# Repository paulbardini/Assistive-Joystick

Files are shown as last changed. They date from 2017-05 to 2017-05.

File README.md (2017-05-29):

# Assistive-Joystick for finite hand movement.

#### This joystick was created as an alternative computer mouse to help a sick family friend. 

#### After battling Guillian-Barre syndrome with a short-term period in induced coma, my friend’s rehabilitation required to re-learn basic hand movements and other physical activities which many of us take for granted.

#### This joystick was designed to sit in the hand while lying in bed. The large button on top of the device reduces the amount of effort required to perform a mouse click, while the joystick creates a more controlled method of positioning the mouse cursor.

#### Apart from helping out a friend, I want this project to be released to the community, within an open source ideology, in hope that this may help others in similar situation, or used in ways that are not intended here.

#### Please – take this idea and recreated it. Modify/redesign it to be used for an alternative reason.  With the help of an open community, this project could assist many people in need.

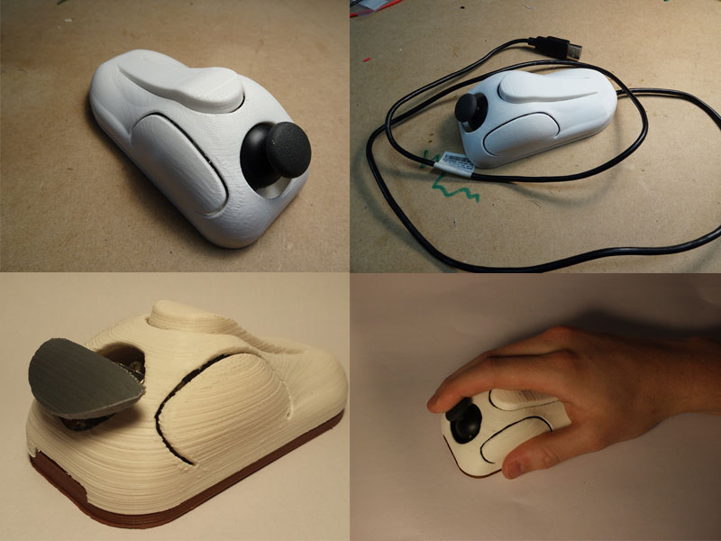
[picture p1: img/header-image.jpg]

>
><b> This project was created by collaborating with the family member. See some of the research photos and discussions.</b>
>### [RESEARCH AND OBSERVATION](https://github.com/paulbardini/Assistive-Joystick/blob/master/Research/Design.md)
>
><b> The large button on the back of the device allows the user to use their palm for the mouse click. The side buttons function by squeezing the device. </b>
><b> A new finger rest was designed to replace the existing joystick knob, allowing the two or three fingers to move the joystick. </b>
>### [IMAGES OF USE](https://github.com/paulbardini/Assistive-Joystick/blob/master/img/Functionality/Use.md)
>
><b> To keep within an open acessible framework, electronic conponents and fabrication was kept within generic conponents and techniques. </b>
><b> Arduino micro controller and stock (very accessible) joystick parts and switches where used to allow for easy replication of the device </b>
>
><b> All CAD source files have been included [link](/CAD%20files).</b>
><b> Please fork this design and/or push changes that helps you and maybe others. </b>
>### [HOW TO MAKE THE ASSISTIVE JOYSTICK - THE HARDWARE](https://github.com/paulbardini/Assistive-Joystick/blob/master/making/README.md)
> 
> ### [HOW TO MAKE THE ASSISTIVE JOYSTICK - THE SOFTWARE](https://github.com/paulbardini/Assistive-Joystick/tree/master/Code)
> 
>
>
***

#### THIS IS AN ONGOING PROJECT AND I AM ASKING FOR HELP TO FURTHER THIS TECHNOLOGY.
#### PLEASE NOTE THAT THIS IS ASSOCIATED WITH A UNIVERSITY RESEARCH PROJECT  
#### PLEASE READ THE FOLLOW ETHIC PROTOCOLS.

****

##### Research Description
This research seeks to better understand the open source framework and how it can be incorporated within the creative arts field to further innovation.
Open source is a paradigm of open collaboration and sharing, where ideas are developed within communities. These communities allow their ideas to be freely available for anyone to replicate, adapt or innovate upon the initial concept. Open source is commonly associated with the computer industry and is often misunderstood to be 'free and accessible software.' However, this definition is limited. Open source, correctly framed, is the dissemination of knowledge, an ideology of openness, transparency and innovation.
To create an understanding of how ideas can be disseminated within the open communities, this research project seeks to experiment with an online collaboration platform called Github, (https://github.com). This platform, traditionally used within software development, allows users to publicly share their work, encouraging collaboration and potential innovation. Although the GitHub is being utilised within other disciplines outside of software, there is great scope to investigate how the creative arts can benefit from this established and tested platform.   
The intention is to use GitHub to disseminate current and future project information, in order to investigate:
-	How people use this information.  Whether the published information is replicated or modified.
-	Ways in which this information is modified. Is the information used in unintentional ways?
GitHub structure allows the research to 
-	Communicate research objectives and information to participation. GitHub facilitates a comprehensive licencing protocol, allowing users to establish licencing agreements. This will also enable the communication of research intentions and information to participants about their involvement within the research project.
-	Follow people's use of the information (within the constraints of the GitHub platform). Through built-in analytics, traffic to GitHub can be tracked and reported.
-	GitHub has built-in chat, commenting and wiki facilities to collaborate with participants. As it is a membership based platform, members can be easily identified and contacted.

##### Participatory information.
THIS GITHUB REPOSITORY IS A UNIVERSITY RESEARCH PROJECT 
This research seeks to better understand the open source framework, and to observe how concepts and ideas, published within this repository, are used. All information within this repository is open for the participant to modify, change and innovate. However, it is encouraged, that all future iterations of this project is to be published within a BRANCH of the master repository. 
Please read the following statement to understand your participatory requirements. 
By BRANCHING – COMMENTING – PULLING - PUSHING – COPYING and other function associated with this GitHub repository, you are agreeing to be a participant of this project. This information should remain intact within any future iterations.
Your confidentiality
All information that identifies the participant within this project will be altered for anonymity, within any publication or reporting i.e. no user name or profile information will be published outside of this repository. For your privacy within GitHub please refer to https://help.github.com/articles/github-privacy-statement/ .
No analysis data from this research will be published within this repository. All research data will be achieved within the appropriate data storage system of Griffith University Australia.
###### Participation is Voluntary
Your participation within this project is voluntary, and you can withdraw from the study at any time. You have the right to delete any of your own contributed data. 
###### Potential Risks
There are no foreseeable risks associated with participation in this research
Questions / further information
All enquiries can be sent to the associated contact details attached to this repository.
The ethical conduct of this research
Griffith University conducts research in accordance with the National Statement on Ethical Conduct in Human Research.  If potential participants have any concerns or complaints about the ethical conduct of the research project they should contact the Manager, Research Ethics on +617 3735 4375 or research-ethics@griffith.edu.au
Communication of Results / Reporting
All participants will be able to request materials relevant to their involvement, during and after the completion of the project.  
Contact Details Research Team
###### Researcher:  Paul Bardini - paul.bardini@griffithuni.edu.au
###### Research Supervisor: Dr Beck Davis - beck.davis@griffith.edu.au

###### Research Data Storage
All research data will be archived within the appropriate data storage system of Griffith University Australia for a period of five years.
Griffith University Research Ethics Clearance Number:  2016/858

<br />This work is licensed under a <a rel="license" href="http://creativecommons.org/licenses/by/4.0/">Creative Commons Attribution 4.0 International License</a>.

https://creativecommons.org/licenses/by/4.0/

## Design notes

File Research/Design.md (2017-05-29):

This project was developed to help a friend rehabitiate from a autoimmune condition Guillain-Barré syndrome (https://www.betterhealth.vic.gov.au/health/conditionsandtreatments/guillain-barre-syndrome)

The project is created within an open source ideology, whereby, all the information to produce this device, is shared for anyone to use, create and modify.

Through research, it was found that the development of such product would usual fall outside the effective time the product would be requires. In other words, by the time the necessary research, development, concepts, prototype and creation occurs the patient, in this case, had already been rehabilitated.

This lends to question whether or not products should be developed in the first place. Well, to answer that question, we need to ask WHO ELSE could benifit from the idea.

#### Observations and Design Intent
The following are images of prototyping - with foam etc - to understand what form the assistive joystick would need to be.

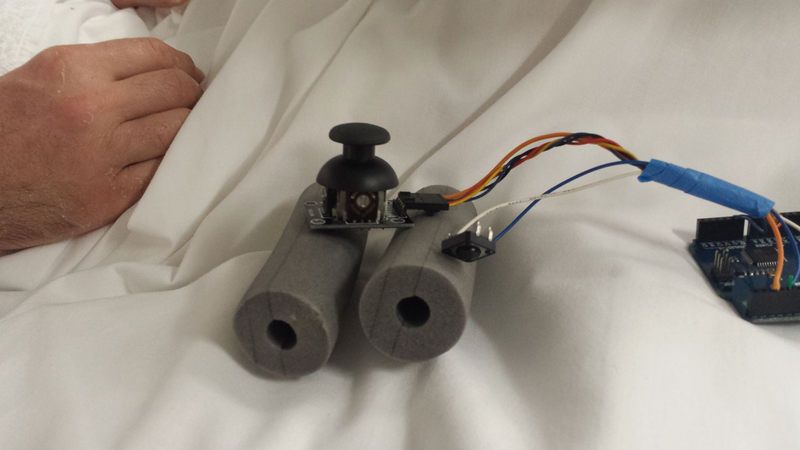
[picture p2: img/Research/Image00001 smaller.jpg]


The strength of the patient was very limited, as was dexterity. 
This led to design the devices to 
- utilised the limited strength of the patient.
- to conrespond to the reaction time and dexerity of the patient.
- ergonomics of hand in a laying positon
- use of open hardware to assist with the acessibility of other coping the device.

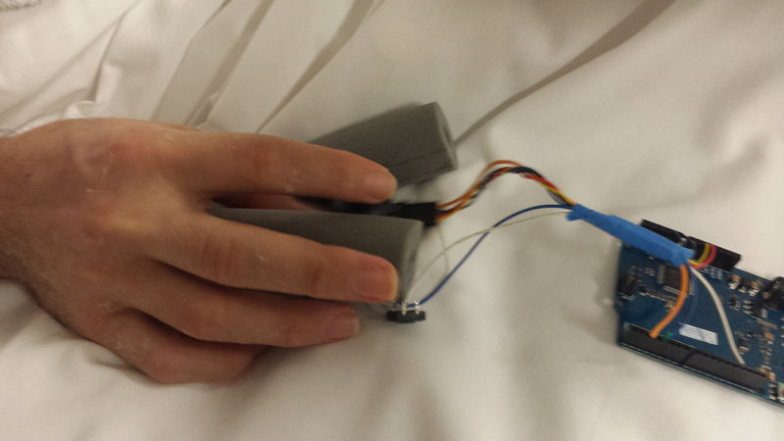
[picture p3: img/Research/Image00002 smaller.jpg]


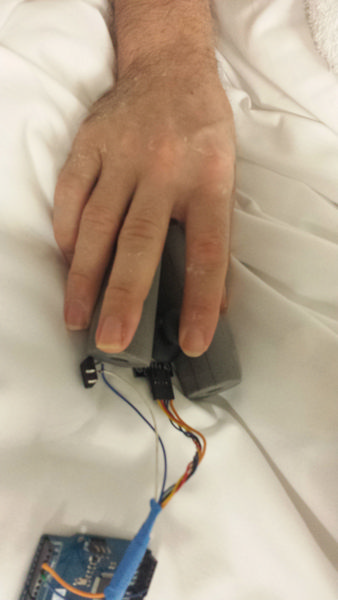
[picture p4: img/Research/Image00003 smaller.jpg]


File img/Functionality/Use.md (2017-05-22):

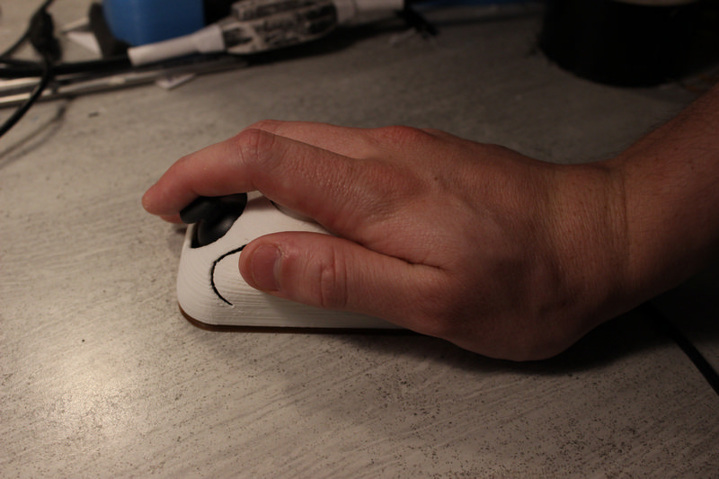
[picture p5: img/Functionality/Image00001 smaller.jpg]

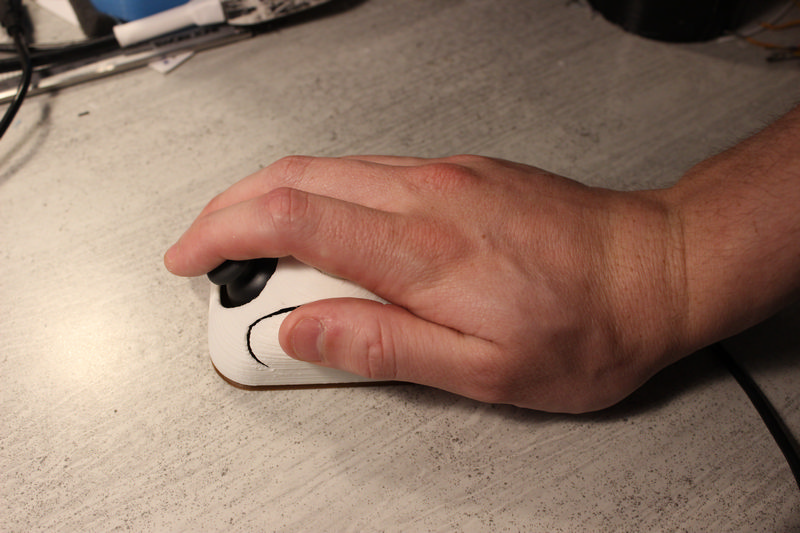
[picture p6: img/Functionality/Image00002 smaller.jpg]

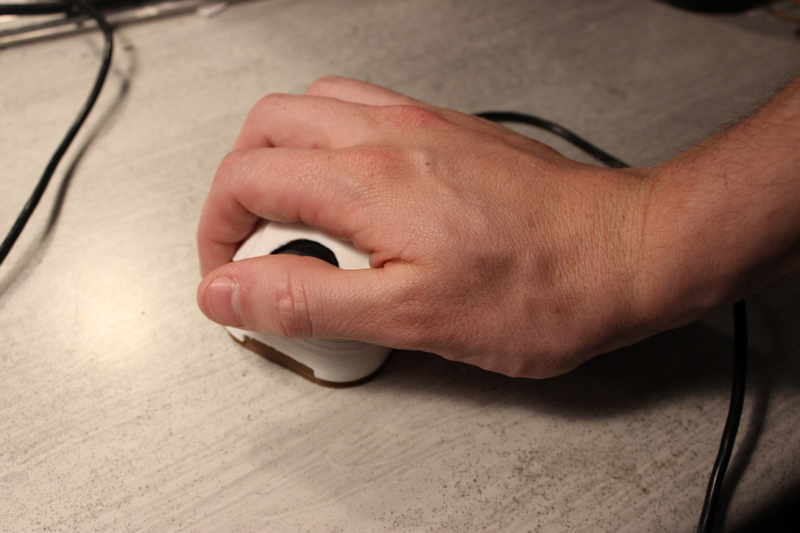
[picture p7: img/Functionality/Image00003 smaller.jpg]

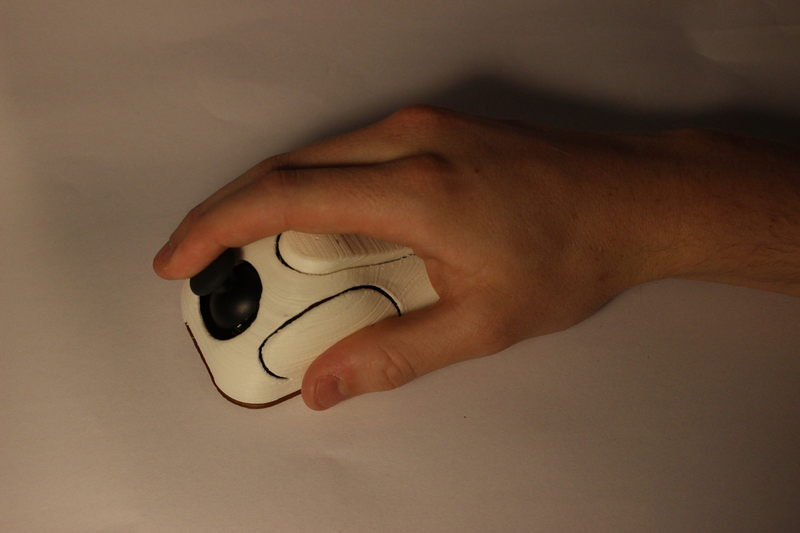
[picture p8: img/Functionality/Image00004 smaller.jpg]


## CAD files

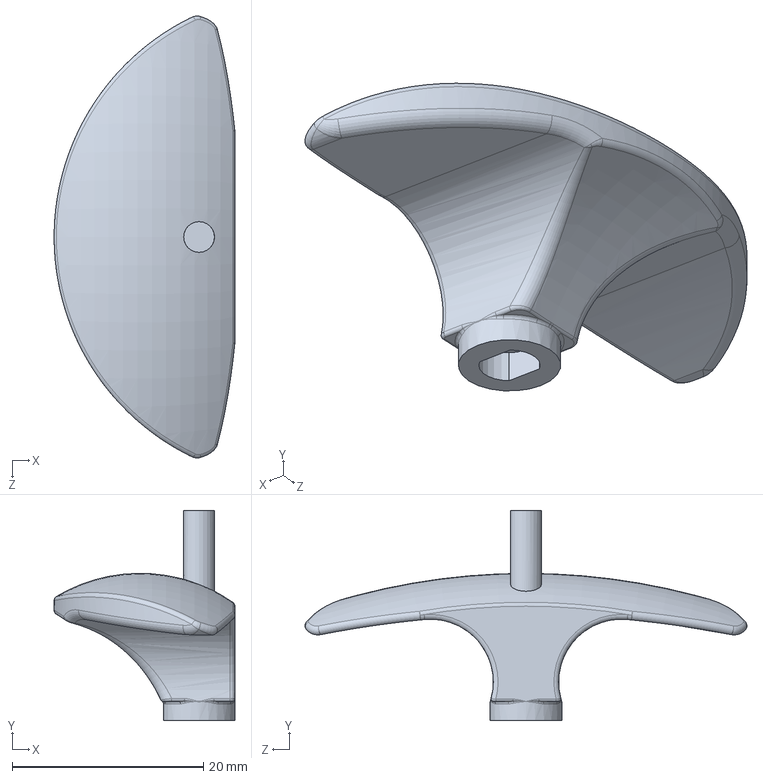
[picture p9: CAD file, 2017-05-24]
CAD files/finger rest convex.SLDPRT
18.9 x 22.0 x 46.3 mm

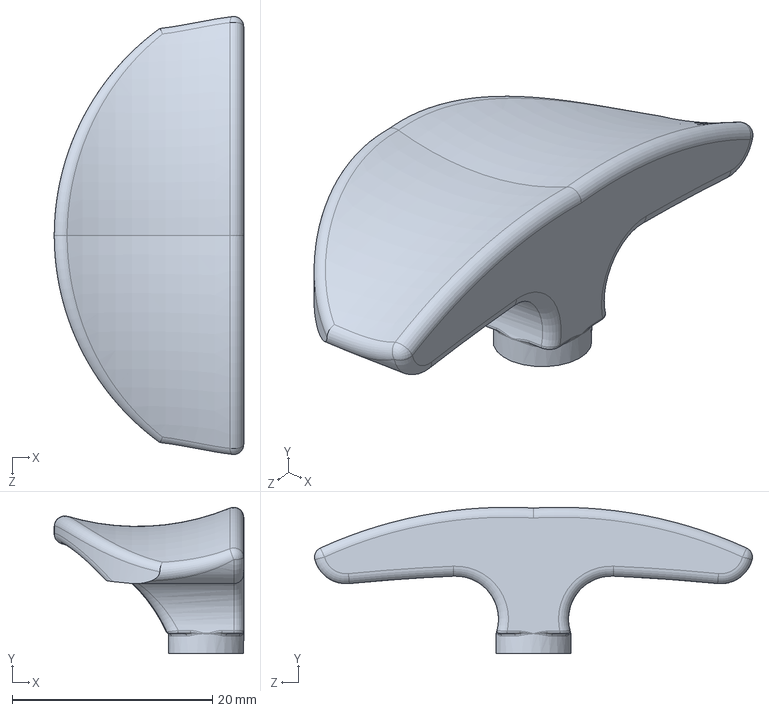
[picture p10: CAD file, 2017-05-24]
CAD files/finger rest 2.SLDPRT
18.9 x 14.6 x 43.7 mm

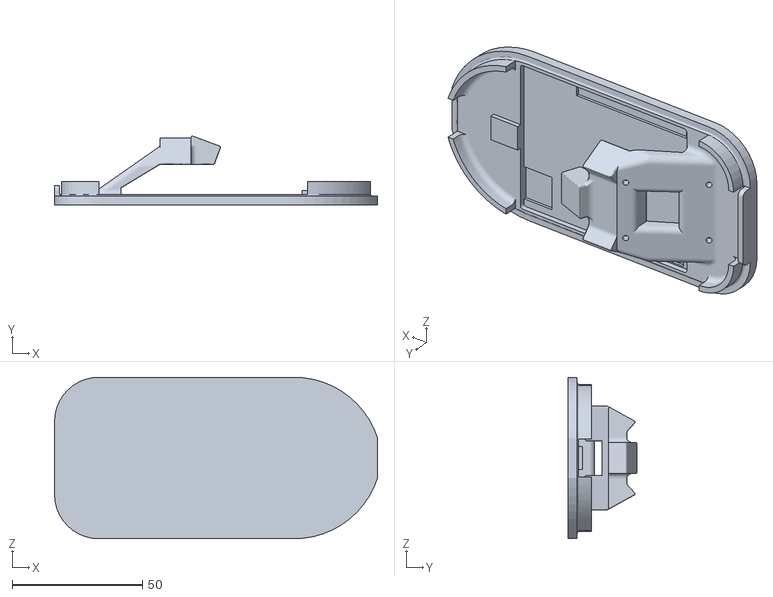
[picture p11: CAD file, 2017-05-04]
CAD files/assistive joystick base.STL
124.0 x 26.4 x 62.0

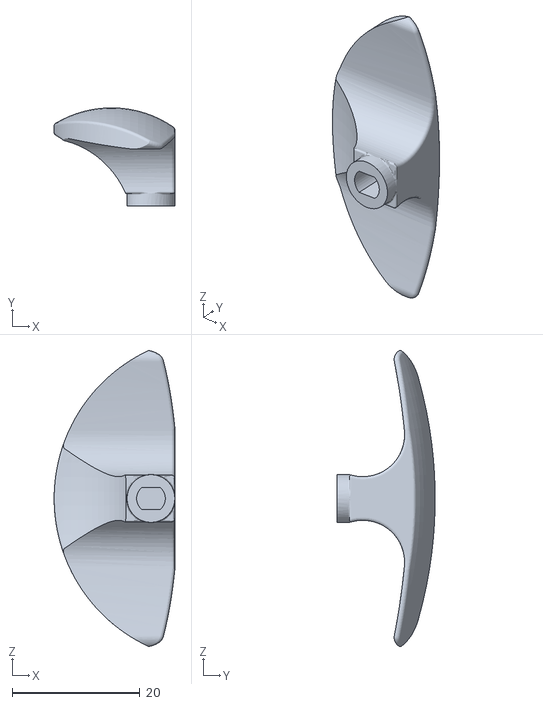
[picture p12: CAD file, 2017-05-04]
CAD files/assistive joystick finger rest.STL
18.9 x 15.4 x 46.4

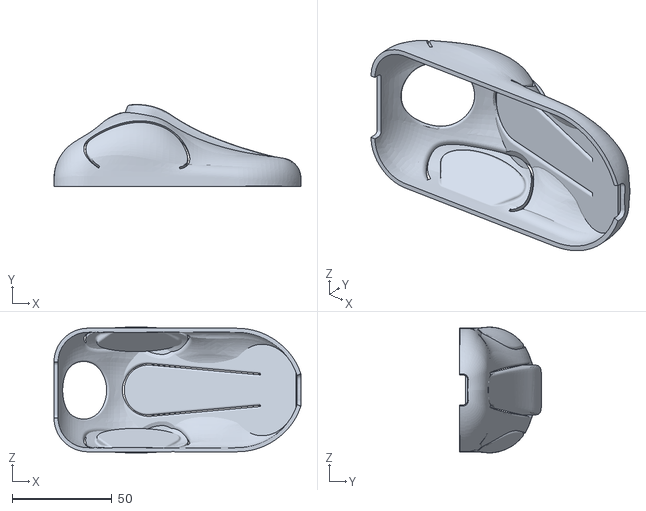
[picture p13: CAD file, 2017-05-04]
CAD files/Assistive Joystick Top Shell.STL
124.0 x 41.1 x 63.2

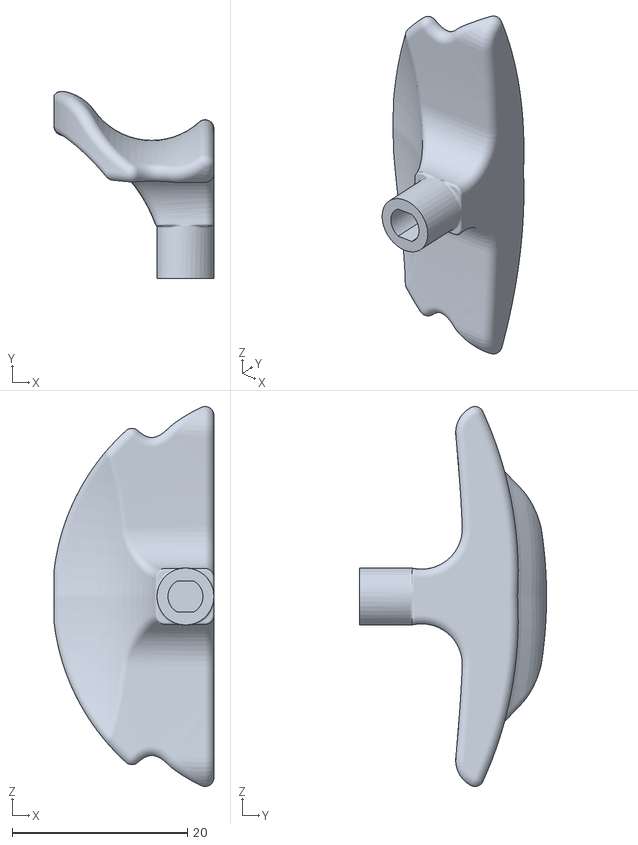
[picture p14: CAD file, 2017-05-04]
CAD files/finger rest.STL
18.2 x 21.4 x 43.4

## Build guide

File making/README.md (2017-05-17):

Hardware

<h1> THIS IS AN ONGOING PROJECT AND I AM ASKING FOR HELP TO FURTHER THIS TECHNOLOGY.</h1>
To Create the Joystick you will require the following materials.

Materials

- Arduino Leonardo - requires the mouse emulator
  - https://www.arduino.cc/en/main/arduinoBoardLeonardo
- Joystick
- 3 tactile push buttons
- hook up cable
- Male Headers

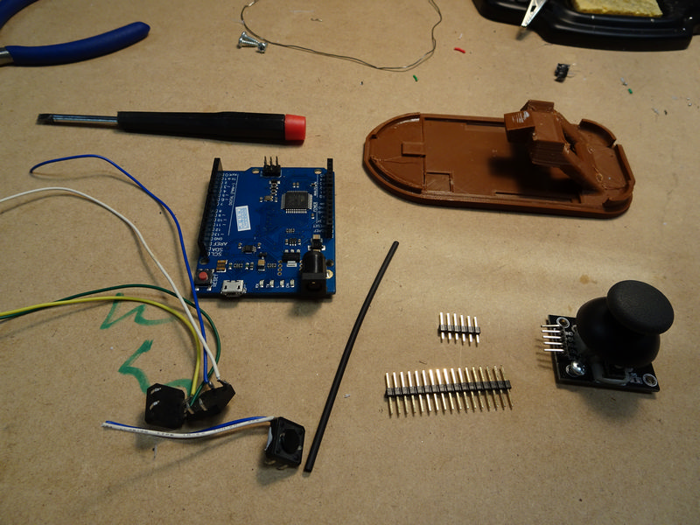
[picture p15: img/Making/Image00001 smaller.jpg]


Tools

- A 3D Printer - or someone to print this for you 
  - Link to STL Files - https://github.com/paulbardini/Assistive-Joystick/tree/master/CAD%20files
  - Link To Thingiverse - http://www.thingiverse.com/thing:1104178/#comment-1287946
  - On-Shape CAD link - https://cad.onshape.com/documents/931052d5d0573c68088a0b20/w/b2adfe2d1f8098bca9e43ab1/e/50dc9f8685308ad67deea490
  
- soldering iron + solder
- wire cutters
- Hot glue gun
- various screws
- screw drivers

<h2> 3D Printing</h2>
You can download the stl file from this link.
https://github.com/paulbardini/Assistive-Joystick/tree/master/CAD%20files

There are two main part to print for the body of the Joystick. I recommend you print these separatley, they take time to print and if it fails then better to loose 1 part and minimal filament.
Both parts will need support, the main body needs a lot of support as most of the body is an overhang. I have done this with an UP Box and the supoort was briliant, much better than my original print as seen on Thingiverse.
I have also printed this in PLA and ABS. Concideration when choosing filament; the mechanical flex in the part is what make the button function.

<h2> Building the electronics</h2>

The joystick uses a Arduino Leonardo - this arduino allows for an intergrated USB HID - in other words it acts like a mouse (or keyboard) 
Attached is 3 tactile buttons and 1 electronic joystick modules. As seen in the picture above.

Below is the Fritzing circuit layout

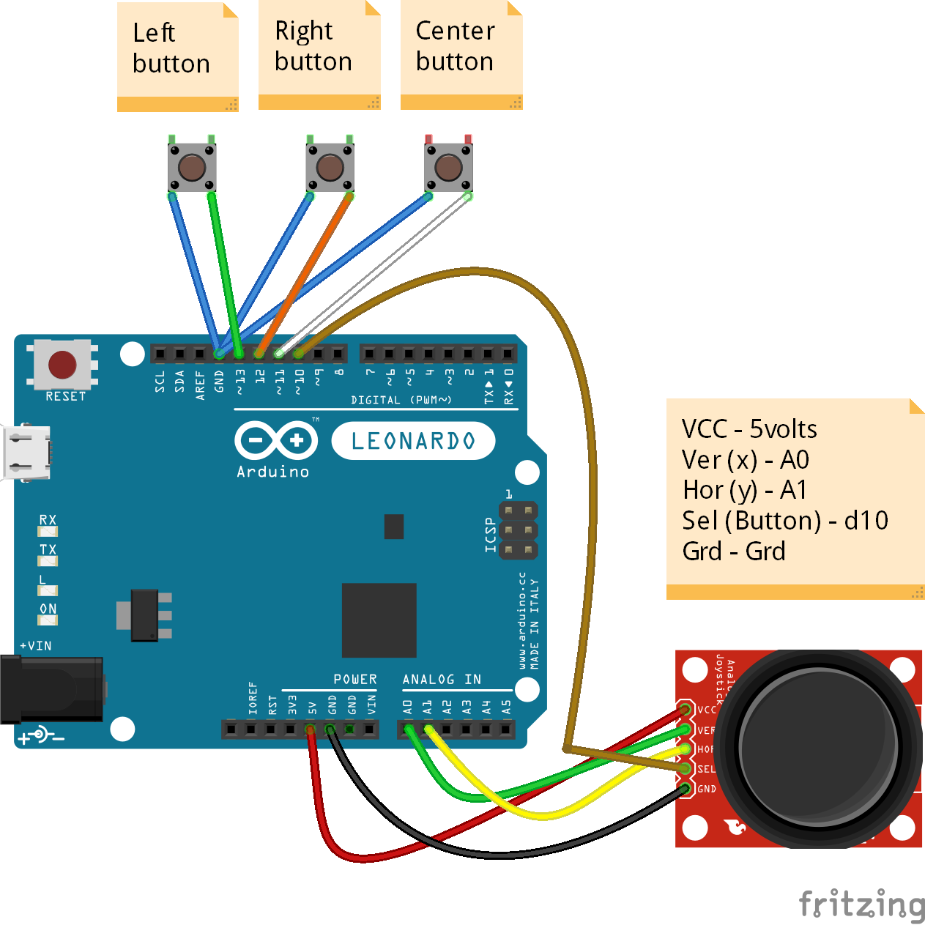
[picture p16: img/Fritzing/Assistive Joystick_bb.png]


<h2> Step 1</h2>

Solder wire onto the Tactile buttons and tie one side together - this will be the button earth/common connection.
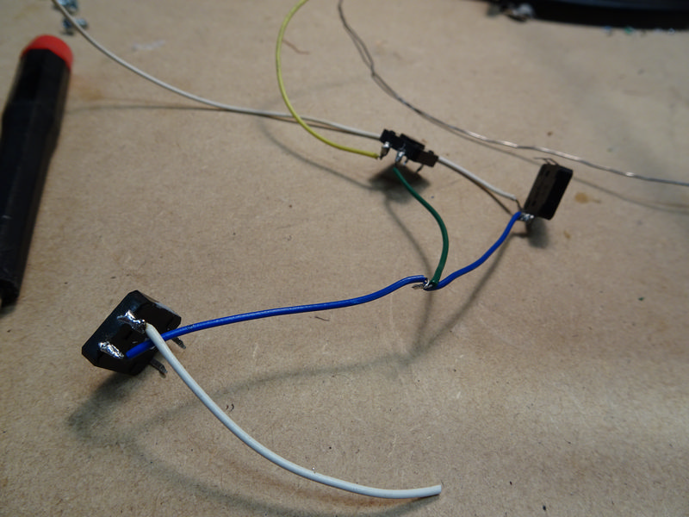
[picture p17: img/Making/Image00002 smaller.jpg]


<h2> Step 2</h2>
Solder all the button wire to a header in order - Common - Button 1 - Button 2 - Button 3.

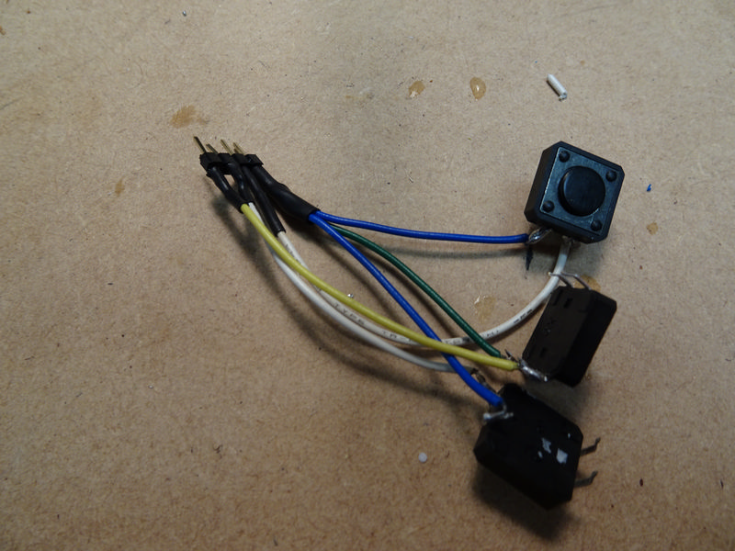
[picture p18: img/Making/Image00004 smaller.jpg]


This will allow the header to plug into the earth - pin13 - pin12 - pin11 of the Arduino. Keeping things neat and tidy.

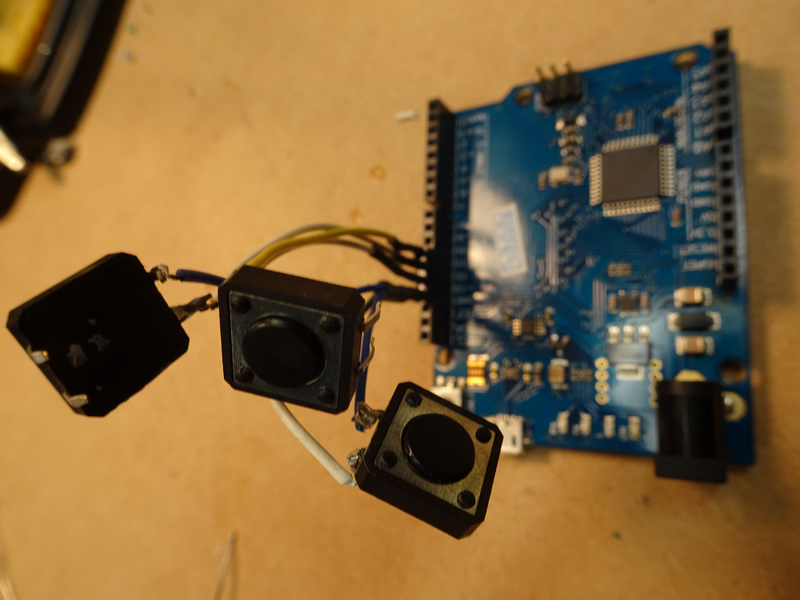
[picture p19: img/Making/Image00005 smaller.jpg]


<h2> Step 3</h2>

<h2> Soldering the joystick.</h2>

The joystick I purchase had header pin pre-connected, this cause problem so I removed them and solder wires straight into the module.
There are 5 connections Earth and VCC (5 volts) X out Y out and the internal switch of the Joystick. 

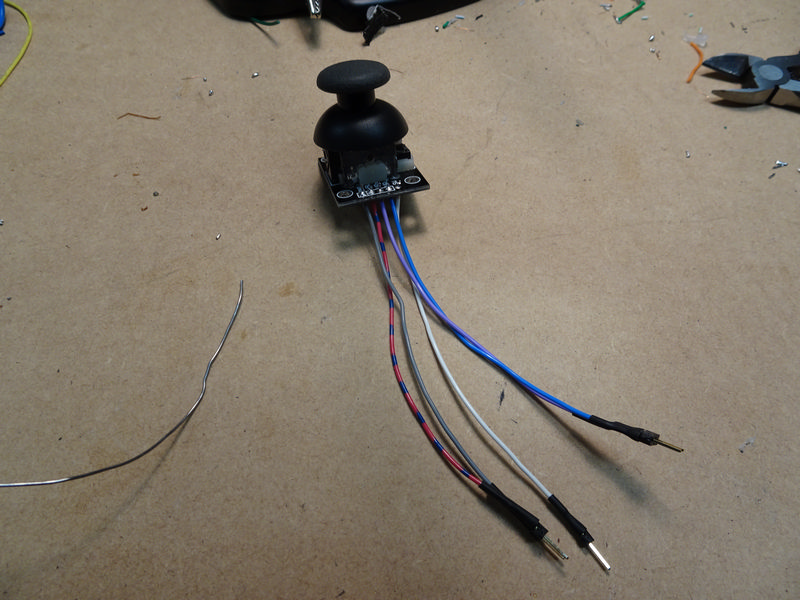
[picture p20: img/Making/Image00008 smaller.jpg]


After soldering the header onto the joystick wires, I used a pair of pliers to remove the platic spacer. This allowed me to bend the header to 90 degrees. There is little room to move with this design, so need to make everyting a tight as possible. As seen in the image below.

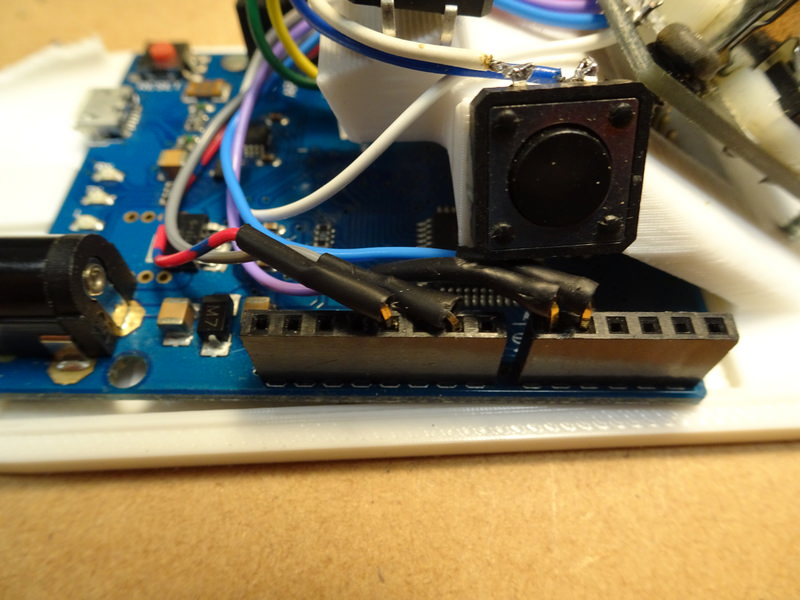
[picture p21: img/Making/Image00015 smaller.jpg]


<h2> Step 4</h2>

<h2> Stuffing it all in</h2>

I did say it was tight, but it does fit. Find a handfull of screw to attach the joystick module to the bottom plate. Be careful, because of the laminating direction of the print, if you use too larger screw it can break/separate the print layer. You also need to pull the joystick module as flat as you can. Be patient - find the rigth screw.

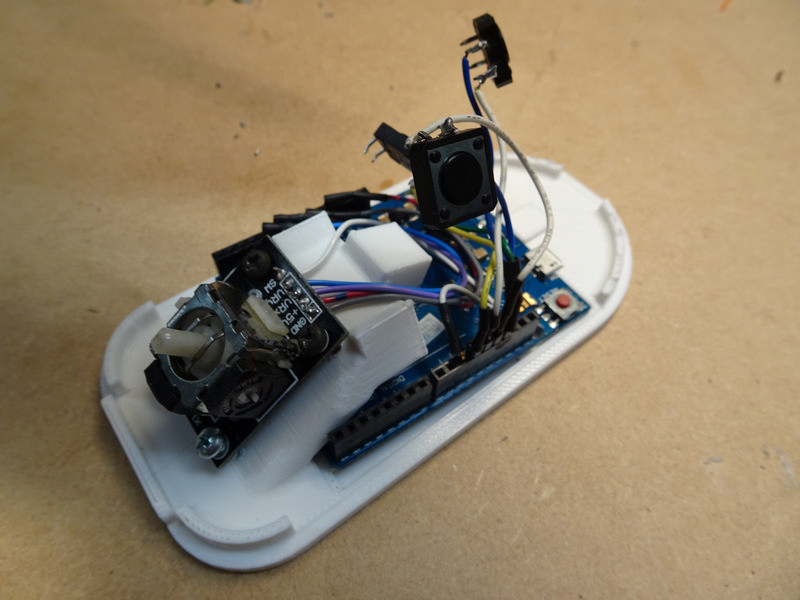
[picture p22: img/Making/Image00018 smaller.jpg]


<h2> Step 5</h2>

<h2> Sticking it down</h2>

I can't say I am a fan of the hot glue gun - overrated in my opinion - but for this case, it works a treat.

Organise your wiring and get everything in the right place before you get glue rage.
I started with the middle button and worked my way round. 

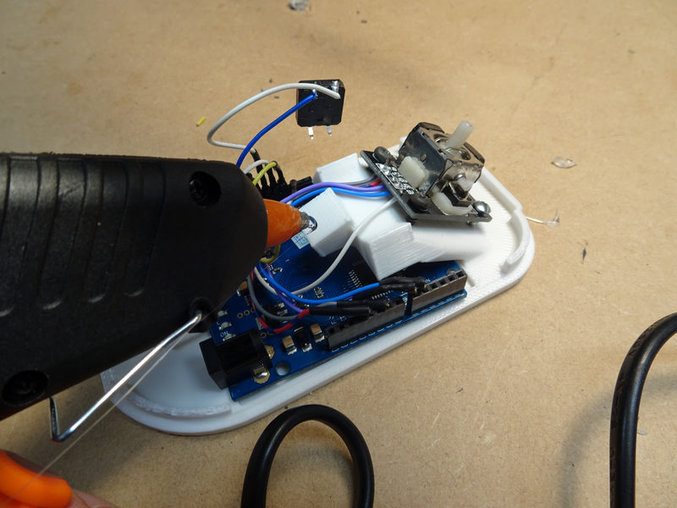
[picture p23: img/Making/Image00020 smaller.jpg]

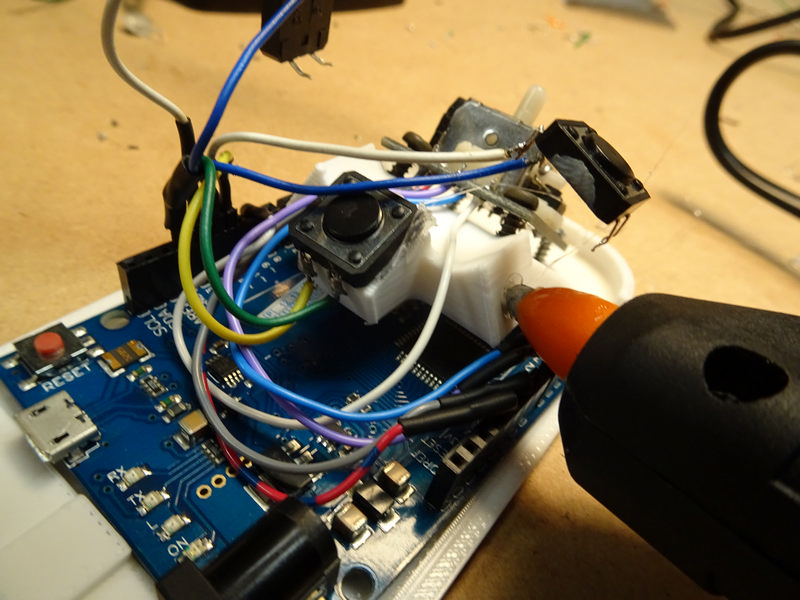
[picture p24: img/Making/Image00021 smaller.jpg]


A bit more glue to hold the wires in place

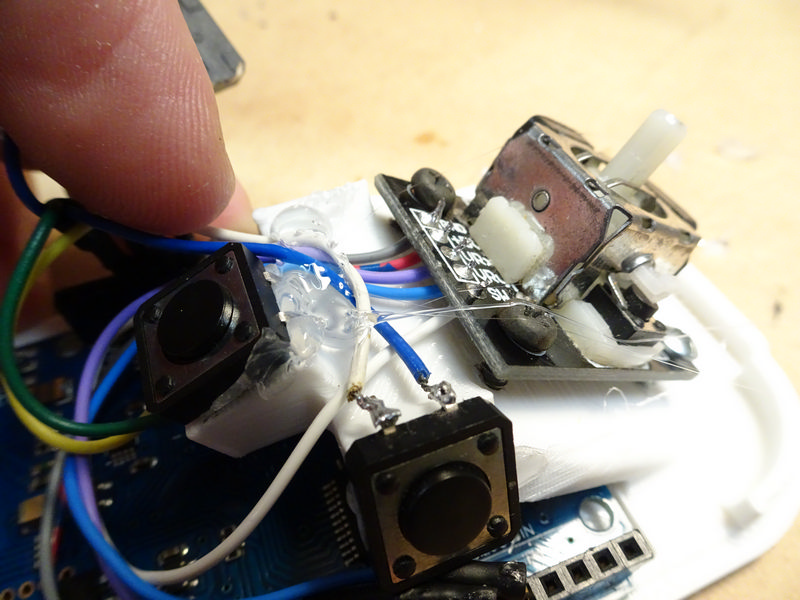
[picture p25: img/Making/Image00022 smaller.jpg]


Now stand back - tend to your burns from the glue gun - and see what you have created.

Behold:

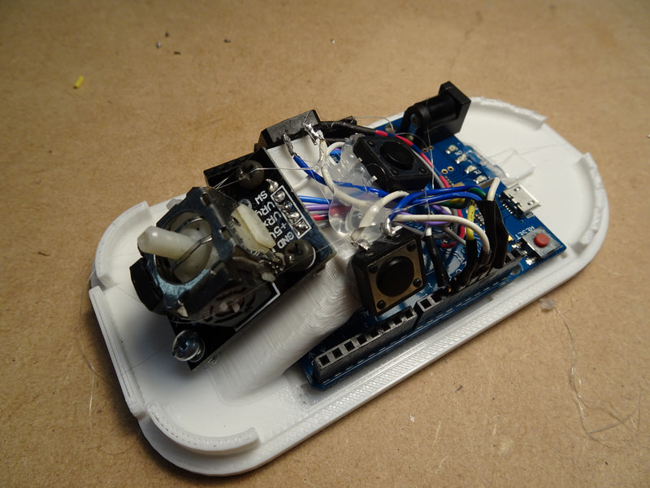
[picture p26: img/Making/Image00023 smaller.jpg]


<h2> Step 6</h2>

<h2> Putting the lid on</h2>

I did have to shave the lip on the base so the top would sit properly. Once the unit is programmed and working I will hot glue a cable in possition and the lid closed. This is what I like about Hot Glue - the ability to get things apart again.

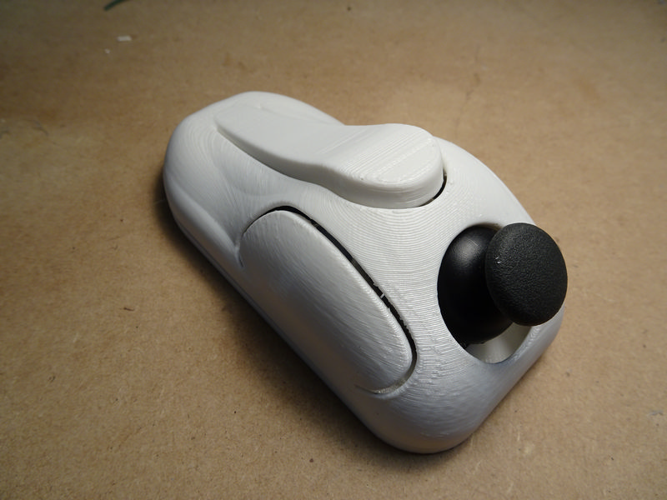
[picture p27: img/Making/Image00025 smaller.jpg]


Great - so now that it is mostly together - there are a few tweeks to get things works.
Jump to this link to see how to calibrate the button contact.

-LINK

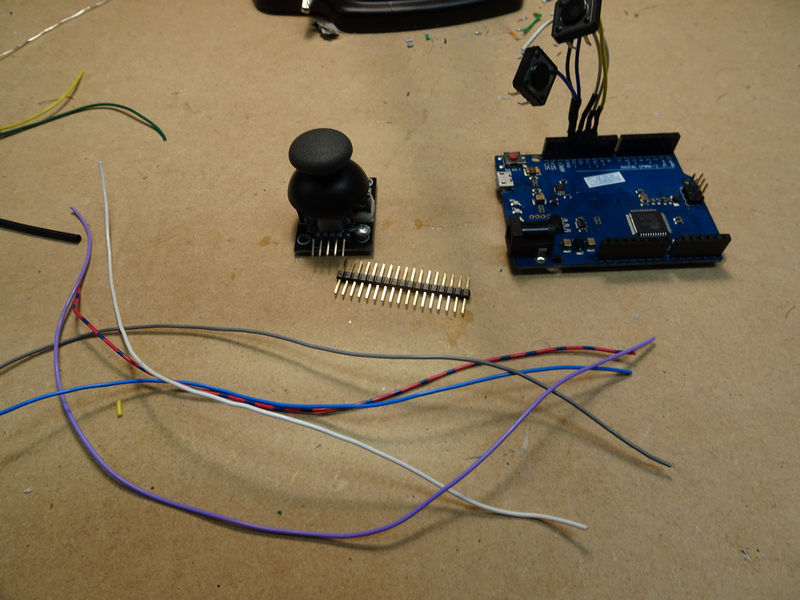
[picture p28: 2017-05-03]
img/Making/Image00007 smaller.jpg

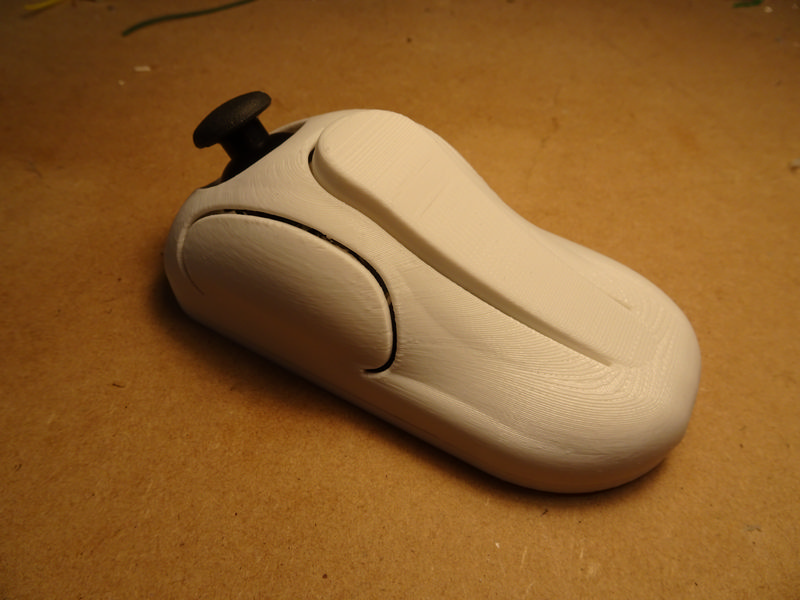
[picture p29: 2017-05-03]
img/Making/Image00027 smaller.jpg

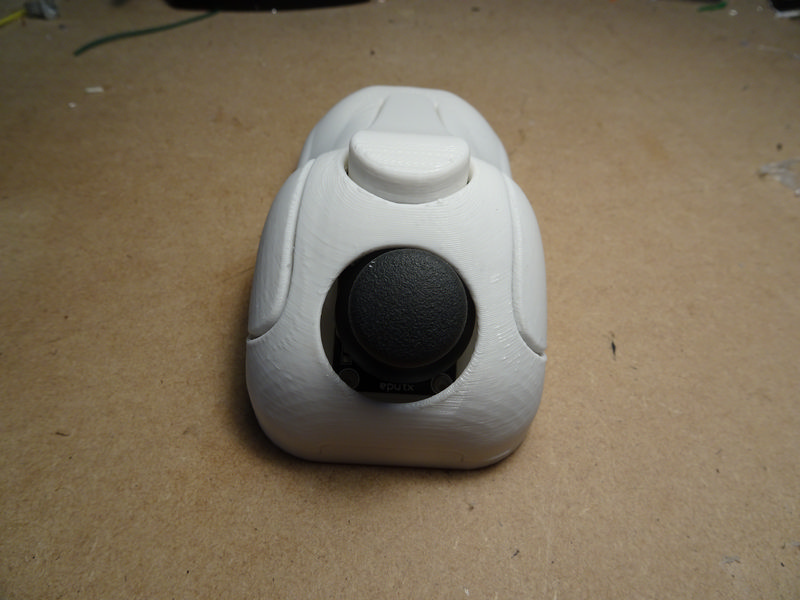
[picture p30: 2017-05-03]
img/Making/Image00026 smaller.jpg

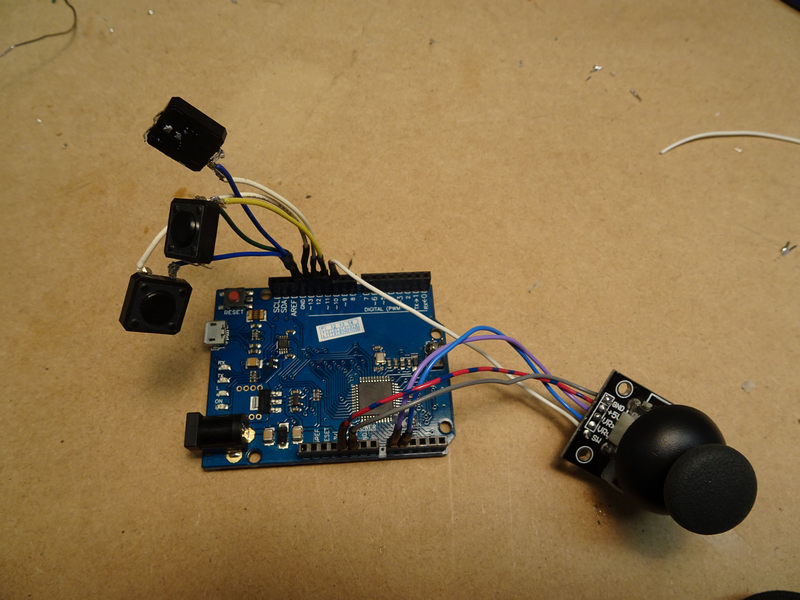
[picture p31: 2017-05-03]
img/Making/Image00011 smaller.jpg

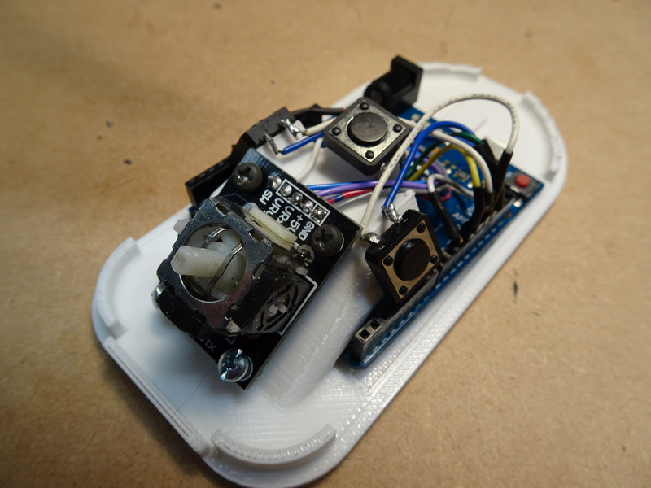
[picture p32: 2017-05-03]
img/Making/Image00013 smaller.jpg

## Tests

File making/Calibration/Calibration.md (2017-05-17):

The unit is together, but you may fing that the buttons and the printed upper body do not contact, and therefore work.
This is due to the fact that not all printers, print the same. 

Therefore - it may seem a bit strange, but I found a glue gun and side cutters fix this problem.

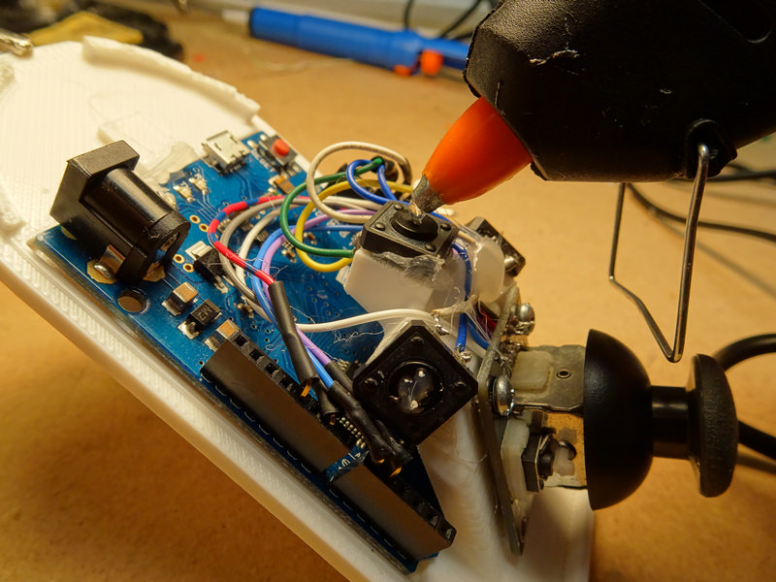
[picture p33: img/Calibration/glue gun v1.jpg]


Take a glue gun and add a dab of glue on top for all the buttons. Don't go over board, just enough to create a small bump.

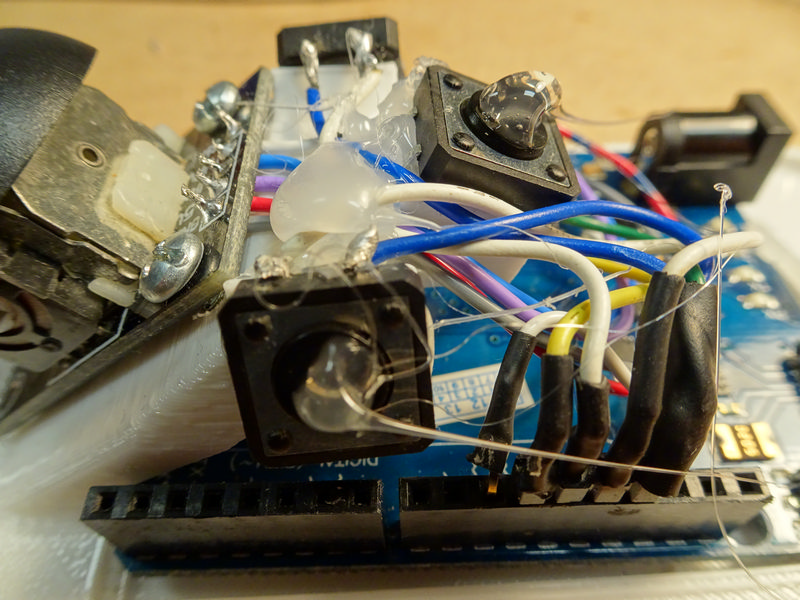
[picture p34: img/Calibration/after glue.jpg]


Use some side cutters to trim the glue. This worked really well for my print. You may need to play around with this.

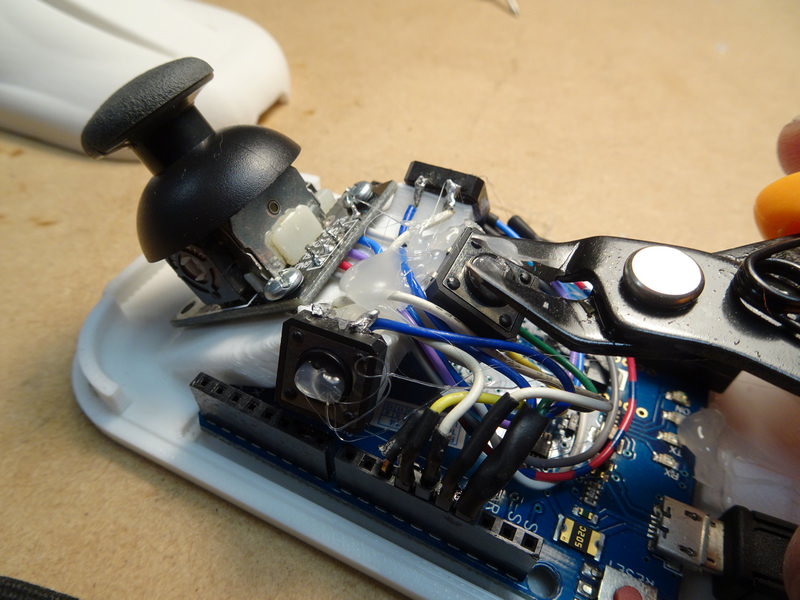
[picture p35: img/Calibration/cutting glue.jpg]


While you have the gun gun in hand, glue in the cable and the lid closed.

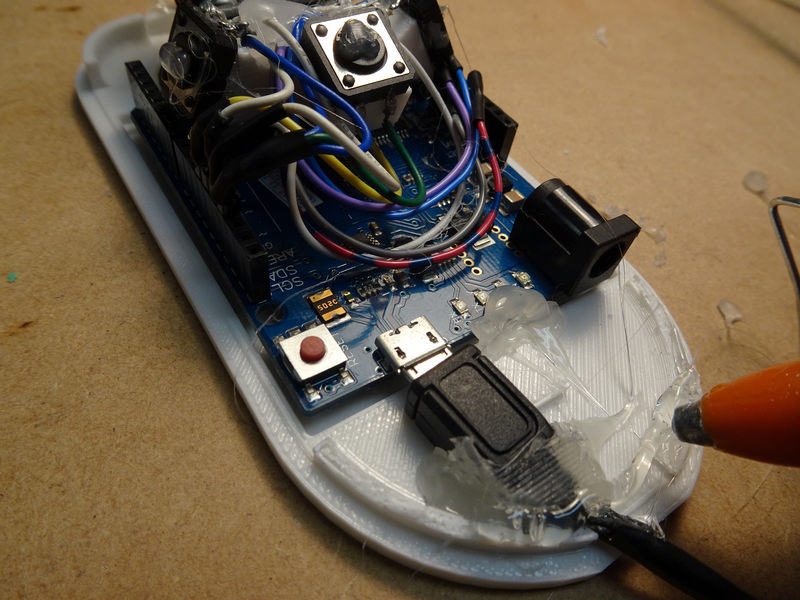
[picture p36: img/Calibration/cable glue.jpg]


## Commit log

2017-04-24 Create On-Shape Cad Link
2017-05-04 Import Cad FIles
    [Assistive Joystick Top Shell.STL, assistive joystick base.STL, assistive joystick finger rest.STL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]
2017-05-24 upload finger rest solidworks
    [finger rest convex.SLDPRT]
2017-05-24 upload cad file
    [finger rest 2.SLDPRT]
2017-05-24 removed file errors and update to 2016 version
    [finger rest convex.SLDPRT]
